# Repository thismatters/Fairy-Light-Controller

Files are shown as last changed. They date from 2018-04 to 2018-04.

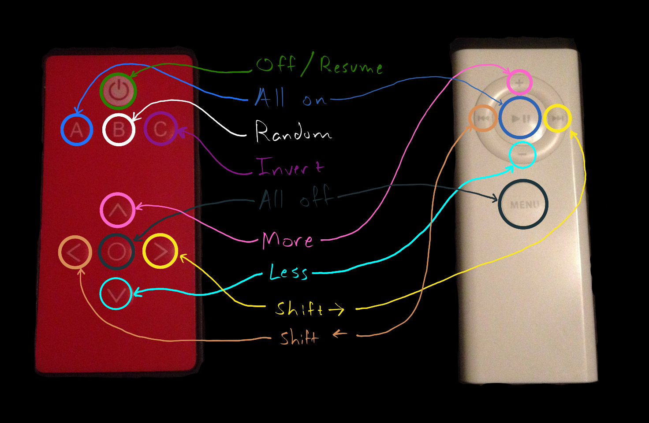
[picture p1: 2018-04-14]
remote_functions.png

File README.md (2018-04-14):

# Fairy Light Controller

Initially when we bought [fairy lights](https://www.amazon.com/gp/product/B00I7M7C40/) (sorry for the amazon link, I hope it stays valid for a while) they came with crappy wall warts which had to be plugged and unplugged daily; these wall warts were of such poor quality that the barrel plug which recieved the light strand would inevitably break. 
Totally unacceptable.
The goal of this project is to provide an easy interface for controlling and powering many strands of LED fairy lights.

## Features

* 40 Watt Power supply,
* ATMega328P,
* IR Reciever and [Remote Control](https://www.sparkfun.com/products/11759) [also works with a little white apple remote if you have one laying around],
* Barrel Plugs for 8 light strands,
* Laser cut acrylic case.

## What's included

* Code for the ATMega328P,
* KiCAD files for the control board ([OSHPark project for this board](https://oshpark.com/shared_projects/VDE5yBSG)),
* Bill of Materials (below),
* SVG files for cutting the case parts.

## Bill of Materials

Here is what you'll need to order to build this thing. I generally order the parts from a few different suppliers due to availability and price so bear with me. You'll also need a board (obvs), you can order some from OSHPark by following the link above, or you can etch your own. Your choice! 

| Part # | Qty | Reference | Description | MFR # (link) | Supplier | Notes |
|---|-----|---|---|---|---|---|
|1|1|C1|Capacitor 100uF (SMD-1206)|[GRM31CD80J107ME39L](https://www.mouser.com/ProductDetail/81-GRM31CD80J107ME9L)|Mouser||
|2|1|C2|Capacitor 10uF (SMD-0805)|[GRM21BC81C106ME15L](https://www.mouser.com/ProductDetail/Murata-Electronics/GRM21BC81C106ME15L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)|Mouser||
|3|1|C3|Capacitor 100nF (SMD-0805)|[100nF 50V 0805](https://www.taydaelectronics.com/100nf-50v-smd-ceramic-chip-capacitor.html)|Tayda|If you order 100 of these they will last you a long time.|
|4|1|C4|Capacitor 1uF (Radial D5L11)|[105CKR100M](https://www.mouser.com/ProductDetail/Illinois-Capacitor-CDE/105CKR100M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)|Mouser||
|5|8|CON1--CON8|Barrel Jack|[KLDX-SMT-0202-AP](https://www.mouser.com/ProductDetail/806-KLDX-SMT0202AP)|Mouser|These are sized to fit the fairy lights linked below.|
|6|1|IC1|Microcontroller|[ATMEGA328P-P](https://www.taydaelectronics.com/atmega328p-pu-atmega328-microcontroller-ic.html)|Tayda|An Arduino chip without the Arduino board. You'll have to have a means to program it (an Arduino board will work nicely for that)|
|7|1|P1|Connector 4POS|[B4PS-VH(LF) (SN)](https://www.digikey.com/product-detail/en/jst-sales-america-inc/B4PS-VH(LF)(SN)/455-1650-ND/926557)|Digi-key|Receive the power onto the board.|
|8|8|Q1--Q8|NPN Darlinton Pair (SOT-223)|[FZT600TA](https://www.mouser.com/ProductDetail/522-FZT600TA)|Mouser||
|9|8|R1--R8|Resistor 0.27 Ohm (Thru-hole)|[MOSX1CT52RR27J](https://www.mouser.com/ProductDetail/660-MOSX1CT52RR27J)|Mouser||
|10|1|R9|Resistor 0 Ohm (SMD-0805)|[0 Ohm 1/8W 1% 0805](https://www.taydaelectronics.com/50-x-smd-chip-resistors-0-ohm-1-8w-1-0805.html)|Tayda|If you order 100 of these they will last you a long time.|
|11|1|R10|Resistor 100 Ohm (SMD-0805)|[100 Ohm 1/8W 1% 0805](https://www.taydaelectronics.com/50-x-smd-chip-resistors-100-ohm-1-8w-1-0805.html)|Tayda|If you order 100 of these they will last you a long time.|
|12|1|R11|Resistor 10k Ohm (SMD-0805)|[10K Ohm 1/8W 1% 0805](https://www.taydaelectronics.com/50-x-smd-chip-resistors-10k-ohm-1-8w-1-0805.html)|Tayda|If you order 100 of these they will last you a long time.|
|13|2|RR1--RR2|Resistor Array (Bussed) 10k Ohm (SIP-9)|[4609X-101-103LF](https://www.mouser.com/ProductDetail/652-4609X-1LF-10K)|Mouser|8 Resistors| 9 Pins|
|14|1|U1|IR Reciever (38 khz)|[TSOP34438](https://www.mouser.com/ProductDetail/522-FZT600TA)|Mouser||
|15|1|X1|Crystal Oscillator (with Caps)|[CSTLS8M00G53-A0](https://www.mouser.com/ProductDetail/81-CSTLS8M00G53-A0)|Mouser||
|16|1|NA|Power Supply 40W|[EPS-45-5-C](https://www.mouser.com/ProductDetail/709-EPS45-5-C)|Mouser||
|17|10|NA|Connector Terminal Crimp-ons|[SVH-41T-P1.1](https://www.digikey.com/product-detail/en/jst-sales-america-inc/SVH-41T-P1.1/455-1319-1-ND/608888)|Digi-key|Those little silver things you have to smash onto your wires.|
|18|2|NA|Connector Housing 4POS|[VHR-4N](https://www.digikey.com/product-detail/en/jst-sales-america-inc/VHR-4N/455-1185-ND/608626)|Digi-key|To get power from the power supply to the board|
|19|1|NA|Connector Housing 3POS|[VHR-3N](https://www.digikey.com/product-detail/en/jst-sales-america-inc/VHR-3N/455-1184-ND/608625)|Digi-key|To get power from the wall to the power supply|
|20|1|NA|Remote Control|[COM-11759](https://www.sparkfun.com/products/11759)|Sparkfun|The software also supports the little white Apple remote control| but the sparkfun one allows more features.|
|21|1|NA|Power Cord||stayonline.com|The power supply insists on being grounded, and I am happy to oblige it. You can use an old PC power cable with one end cut off (choose wisely), or you can order to length.|
|22|8|NA|Fairy Lights|[B00I7M7C40](https://www.amazon.com/gp/product/B00I7M7C40/)|Amazon|It is pretty vital to get the ones with the barrel power connector that matches the barrel jacks (Item 5). Minimum 1, maximum 8|
|23|1|NA|Battery for Remote Control|CR2025|Lots of places|You figure it out|
|24|1|NA|28 pin DIP IC Socket|[28 pin DIP IC Socket](https://www.taydaelectronics.com/28-pin-dip-ic-socket-adaptor-solder-type.html)|Tayda|This is what you'll actually solder to the board. Cram the ATMega328 into this.

## The Case

The case is cut from 0.177 inch thick acyrlic sheet using a laser cutter. The [specific laser cutter](http://atxhs.org/wiki/Hosted/10000045) I used is at the ATX Hackerspace; it does not compensate for kerf so the files themselves compensate for the laser width. The case parts should fit together snugly so no adhesive is needed for assembly, although the little bits for wall mounting will need to be bonded onto the bottom so a little cyanoacrylate adhesive will be useful.

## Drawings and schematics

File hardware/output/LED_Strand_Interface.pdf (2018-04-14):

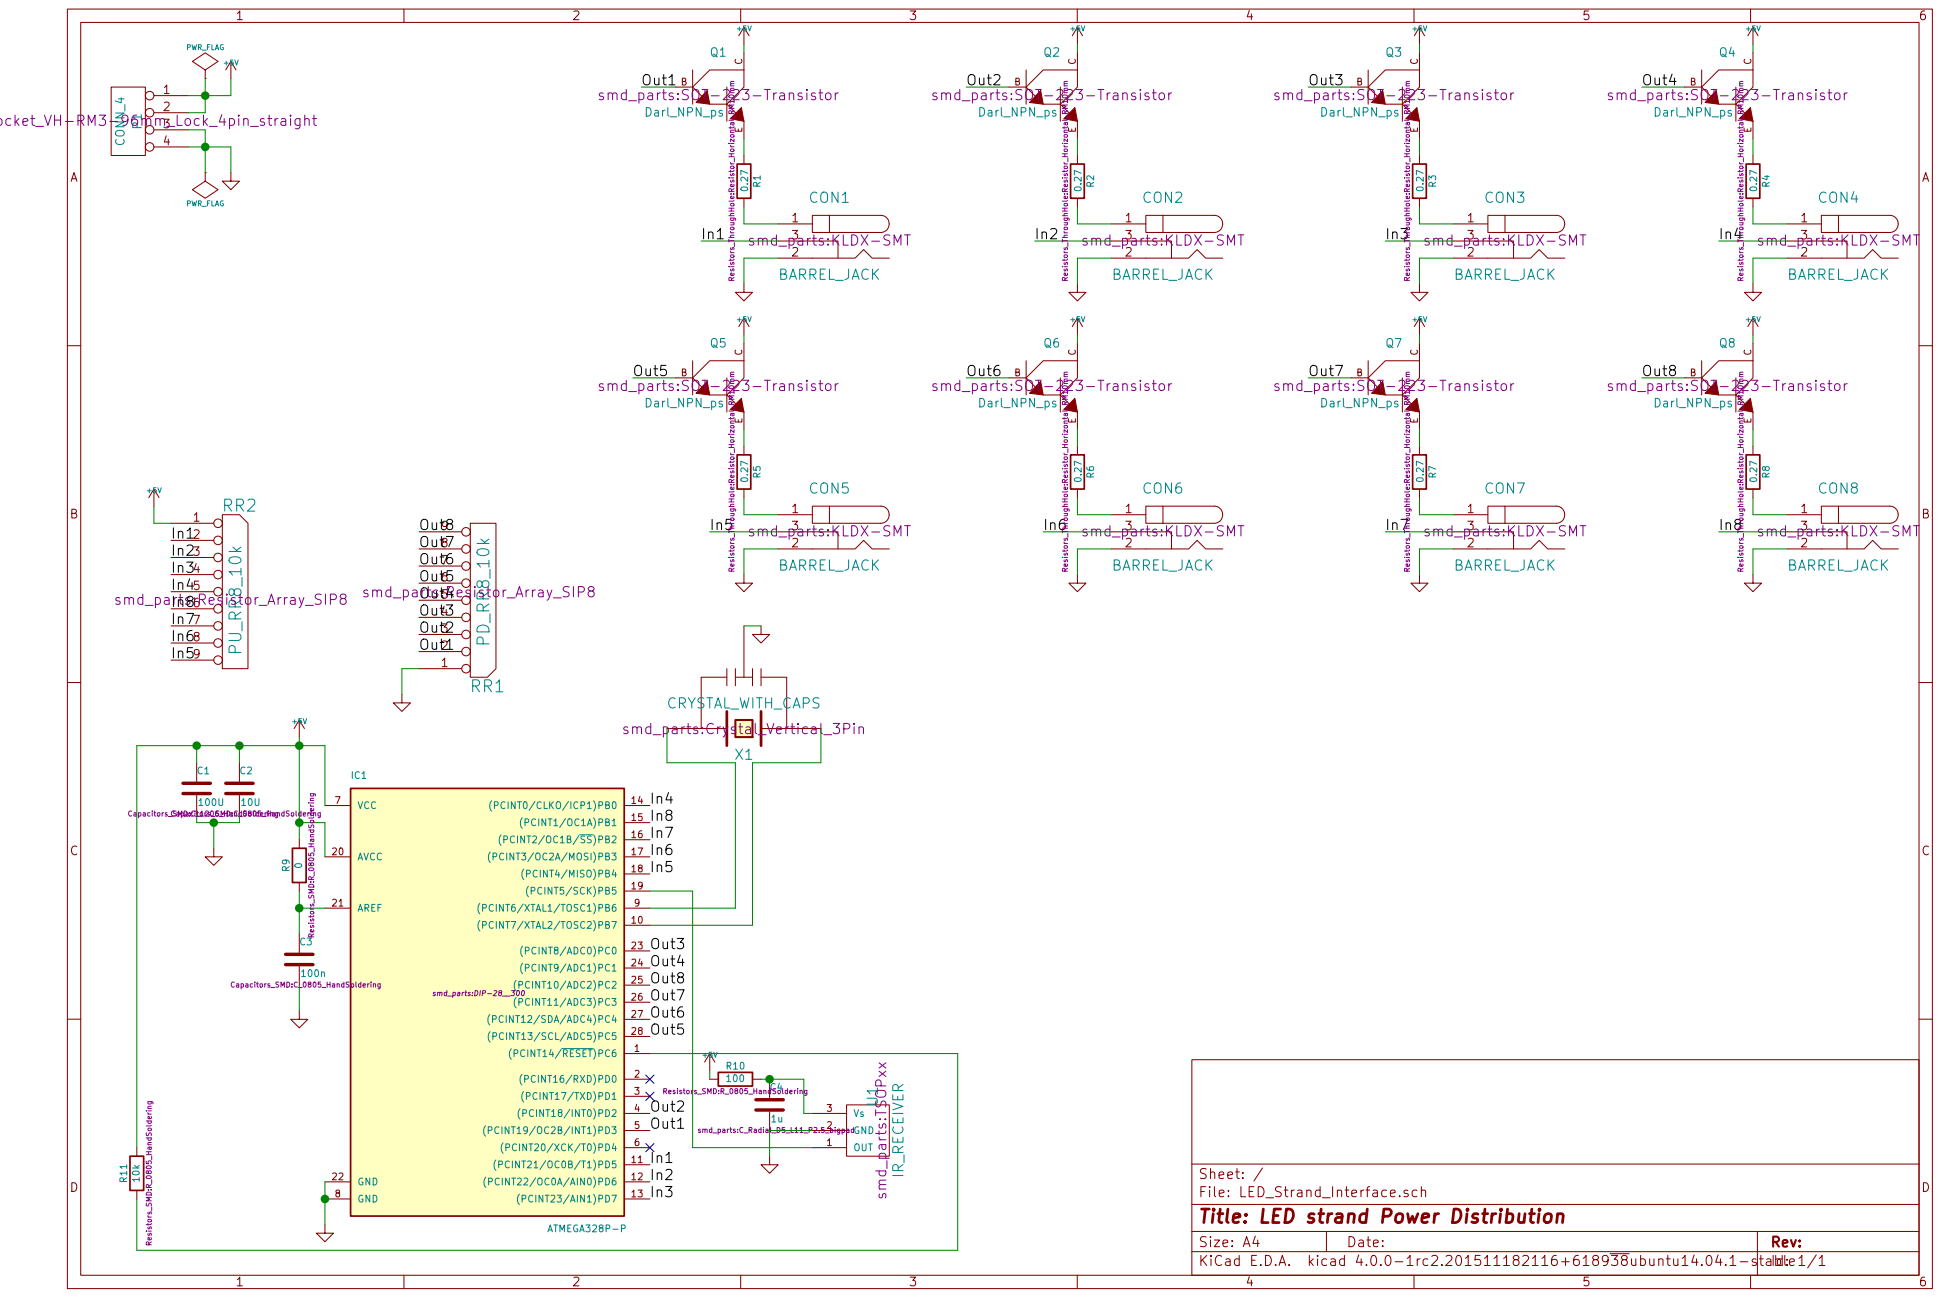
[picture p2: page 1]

File: LED_Strand_Interface.sch Sheet: /
Id: 1/1 Title: LED strand Power Distribution

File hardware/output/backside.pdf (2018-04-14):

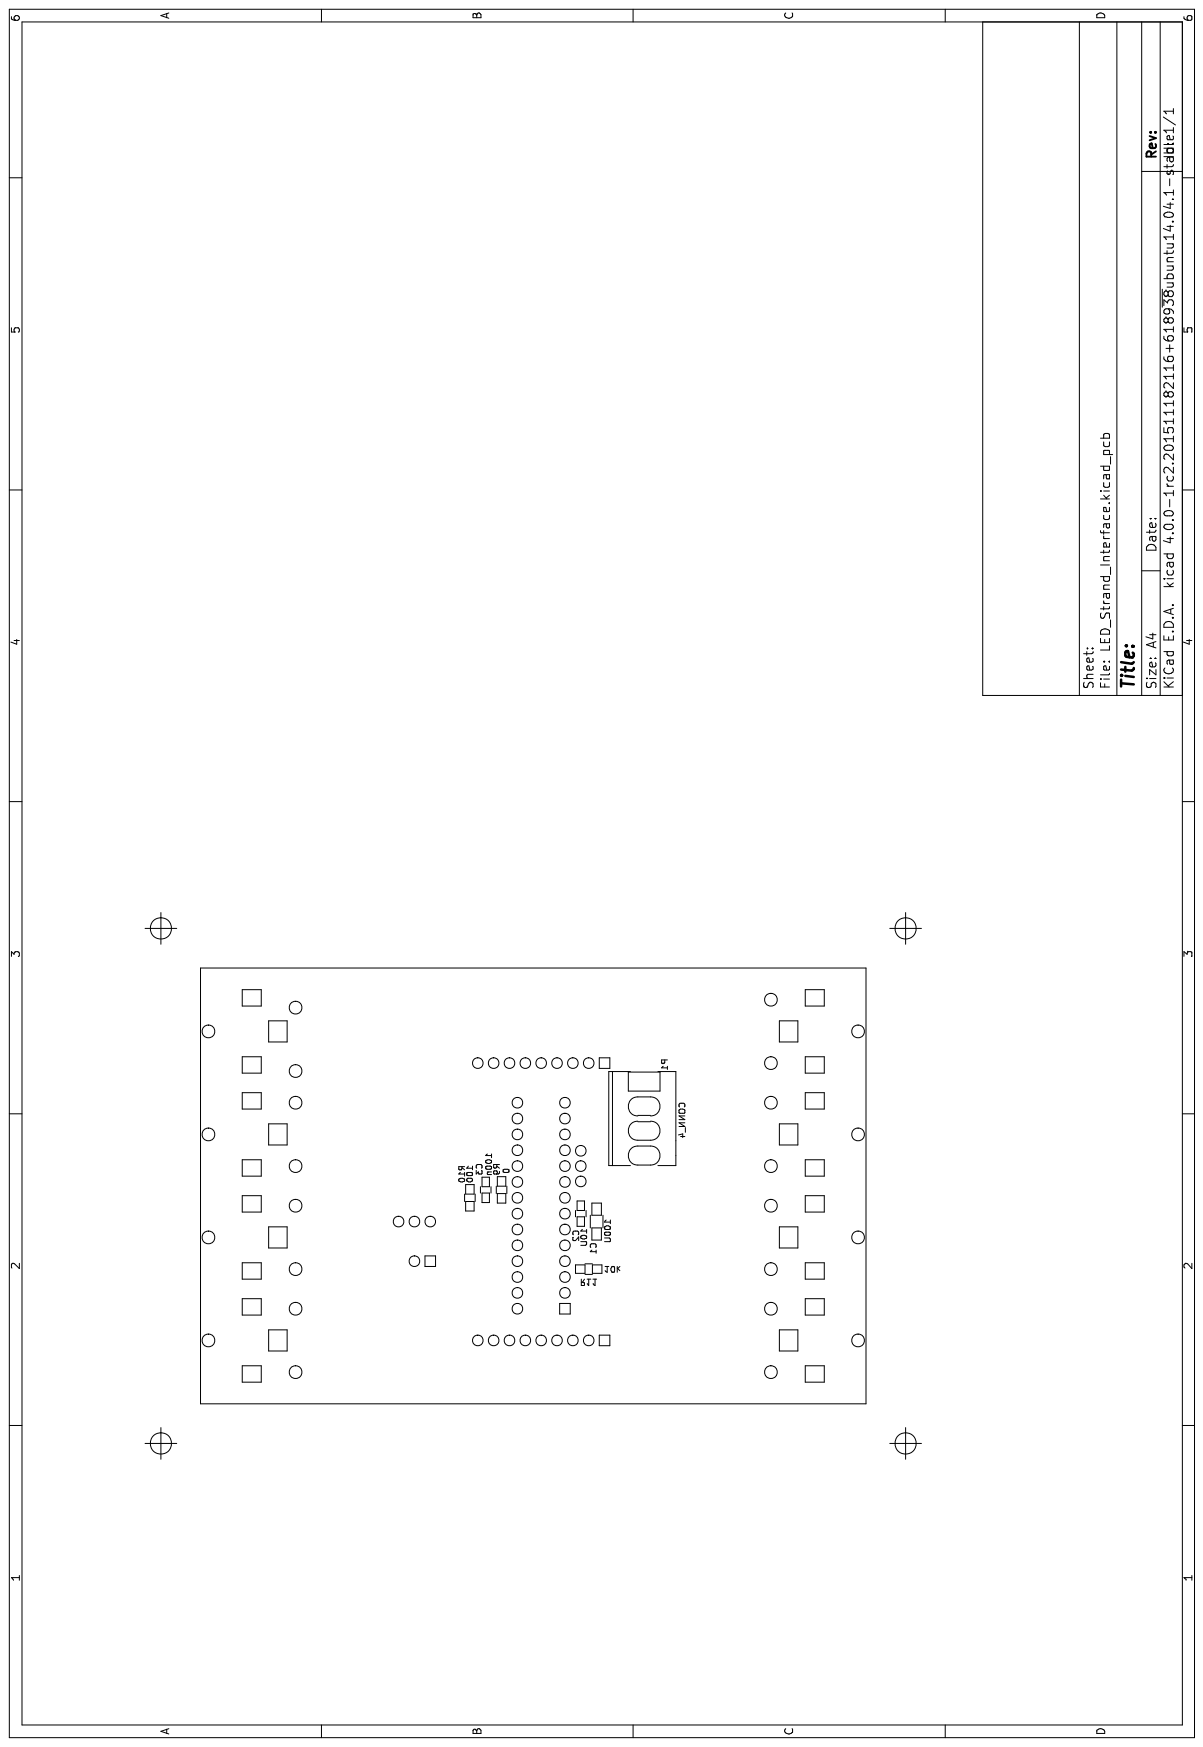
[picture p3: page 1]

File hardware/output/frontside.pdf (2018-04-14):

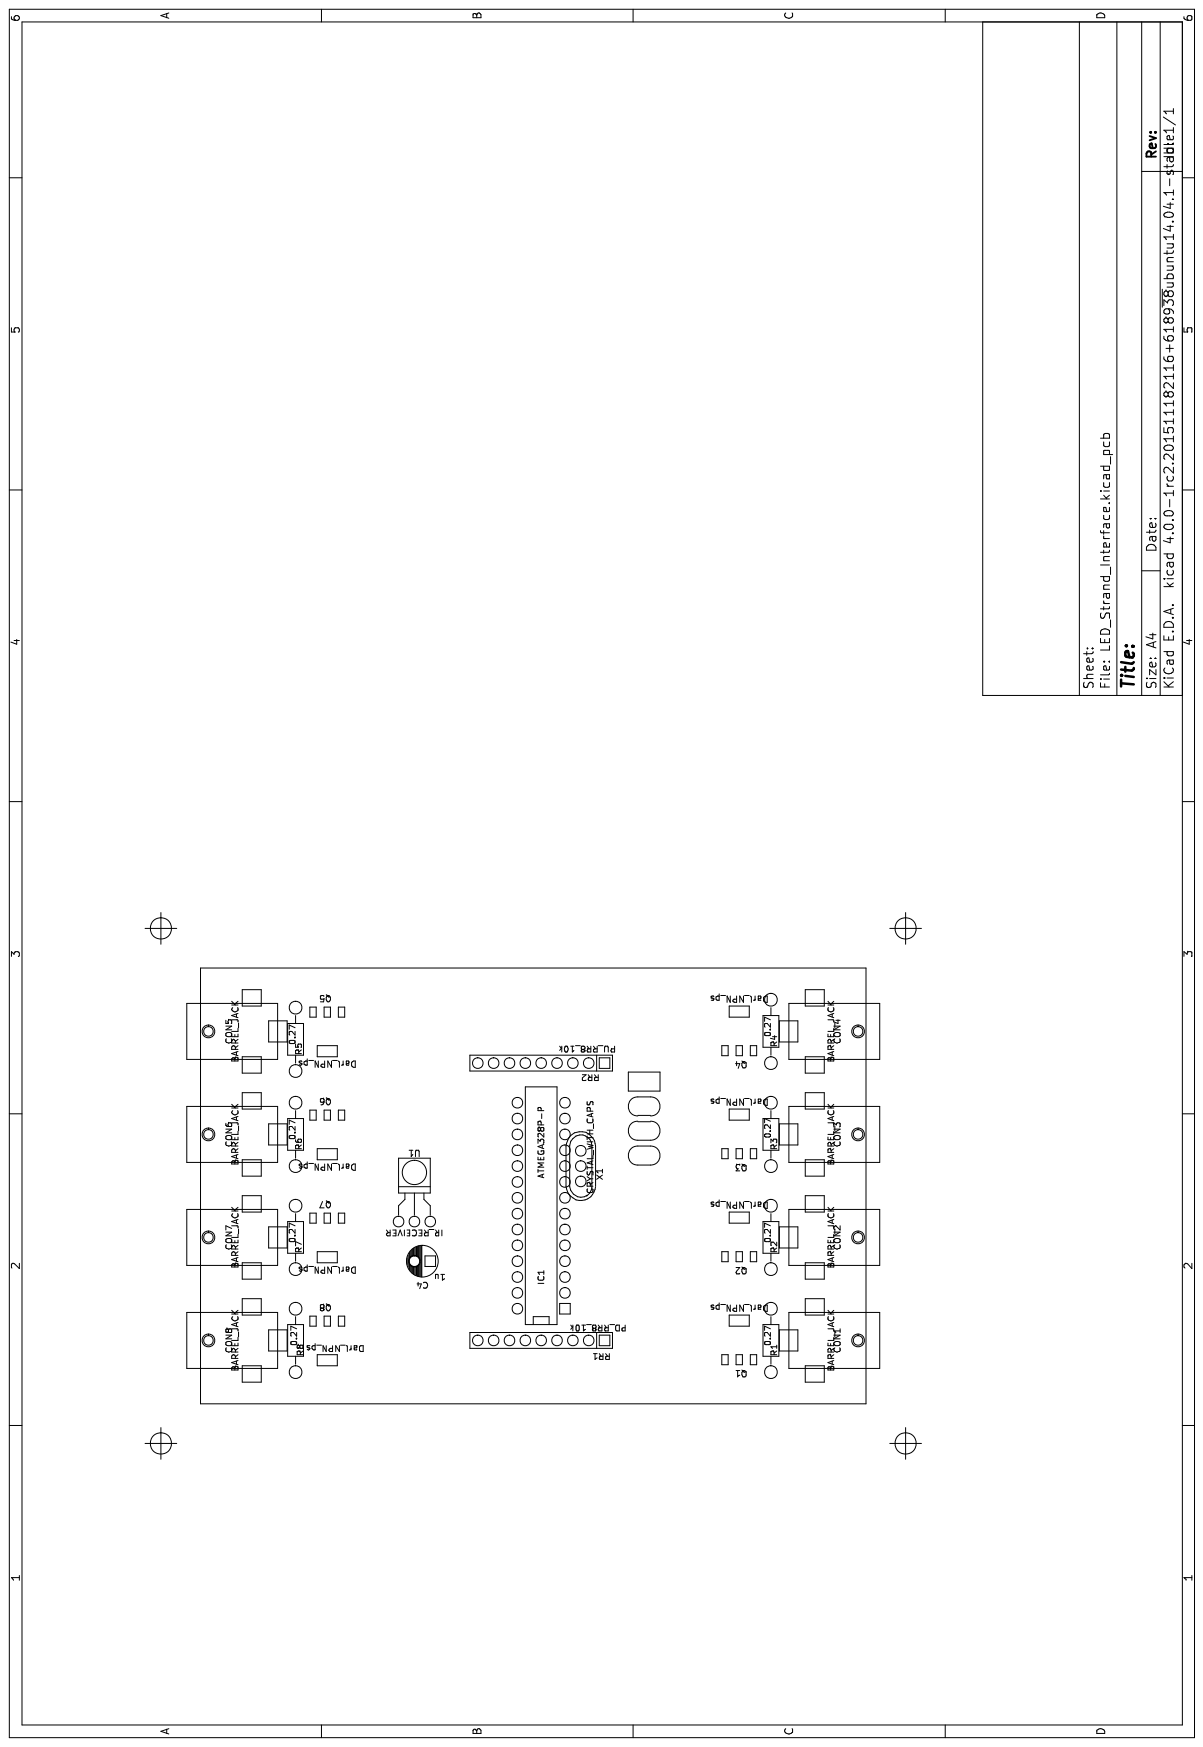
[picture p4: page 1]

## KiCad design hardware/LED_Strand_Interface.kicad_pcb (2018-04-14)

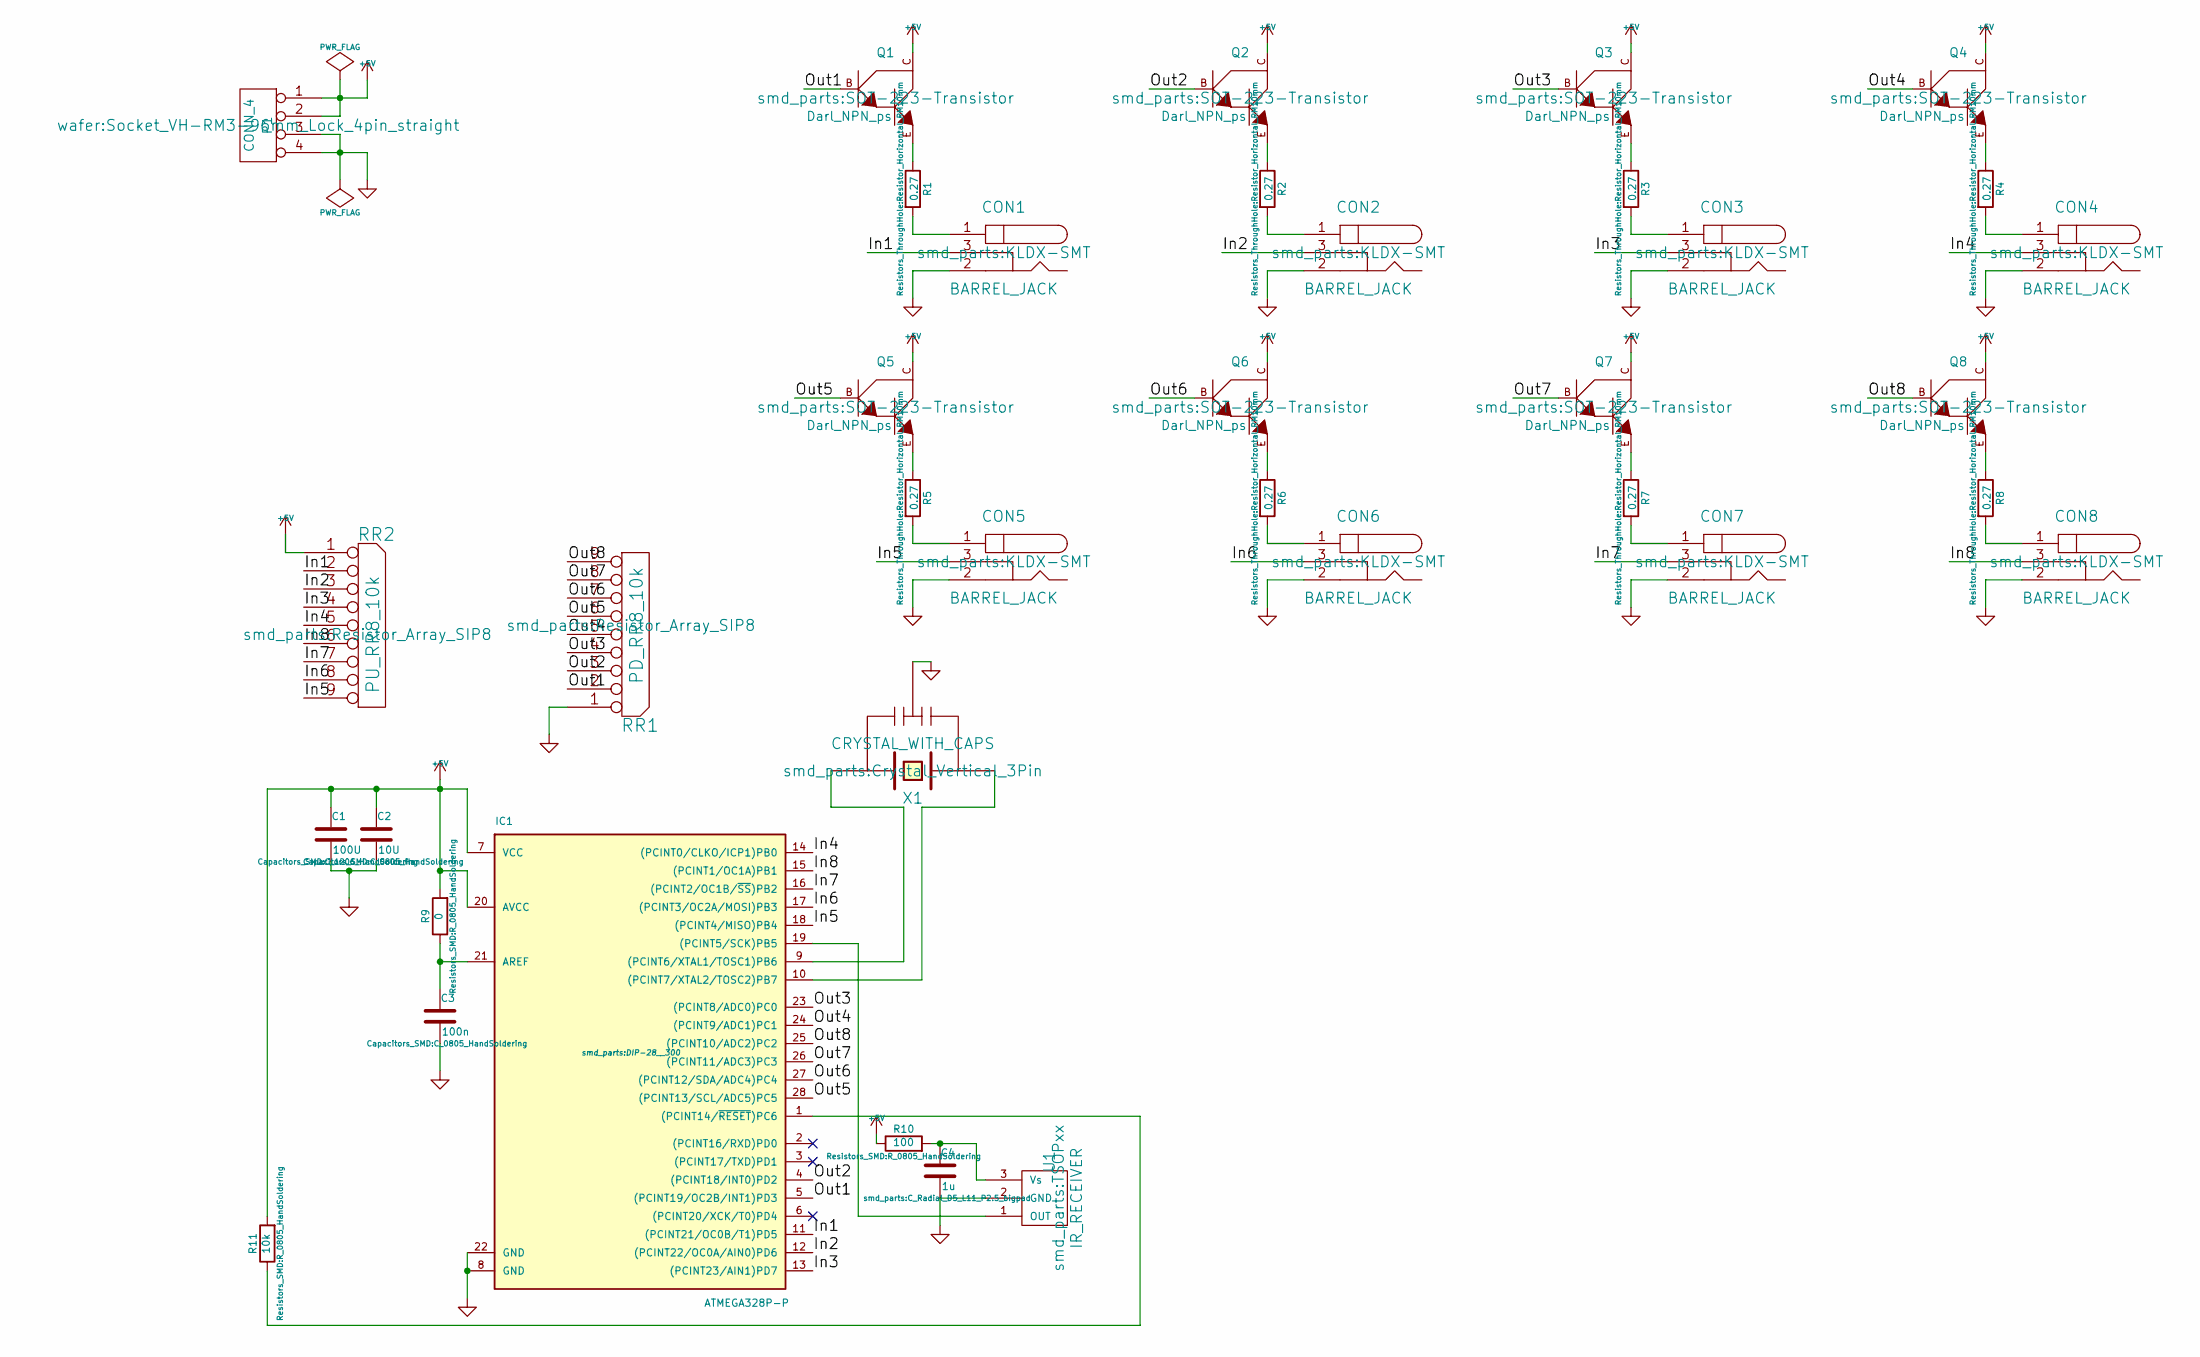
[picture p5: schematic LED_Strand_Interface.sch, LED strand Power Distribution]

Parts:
C1: 100U; C_1206_HandSoldering
C2: 10U; C_0805_HandSoldering
C3: 100n; C_0805_HandSoldering
C4: 1u; C_Radial_D5_L11_P2.5_bigpad
CON1, CON2, CON3, CON4, CON5, CON6, CON7, CON8: BARREL_JACK; KLDX-SMT
IC1: ATMEGA328P-P; DIP-28__300
P1: CONN_4; Socket_VH-RM3-96mm_Lock_4pin_straight
Q1, Q2, Q3, Q4, Q5, Q6, Q7, Q8: Darl_NPN_ps; SOT-223-Transistor
R1, R2, R3, R4, R5, R6, R7, R8: 0.27; Resistor_Horizontal_RM10mm
R9: 0; R_0805_HandSoldering
R10: 100; R_0805_HandSoldering
R11: 10k; R_0805_HandSoldering
RR1: PD_RR8_10k; Resistor_Array_SIP8
RR2: PU_RR8_10k; Resistor_Array_SIP8
U1: IR_RECEIVER; TSOPxx
X1: CRYSTAL_WITH_CAPS; Crystal_Vertical_3Pin

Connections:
+5V: C1.1, C2.1, IC1.7 (VCC), IC1.20 (AVCC), P1.1, P1.2, Q1.C, Q2.C, Q3.C, Q4.C, Q5.C, Q6.C, Q7.C, Q8.C, R9.2, R10.1, R11.2, RR2.1 (COM)
/In1: CON1.3, IC1.11 ((PCINT21/OC0B/T1)PD5), RR2.2
/In2: CON2.3, IC1.12 ((PCINT22/OC0A/AIN0)PD6), RR2.3
/In3: CON3.3, IC1.13 ((PCINT23/AIN1)PD7), RR2.4
/In4: CON4.3, IC1.14 ((PCINT0/CLKO/ICP1)PB0), RR2.5
/In5: CON5.3, IC1.18 ((PCINT4/MISO)PB4), RR2.9
/In6: CON6.3, IC1.17 ((PCINT3/OC2A/MOSI)PB3), RR2.8
/In7: CON7.3, IC1.16 ((PCINT2/OC1B/~SS~)PB2), RR2.7
/In8: CON8.3, IC1.15 ((PCINT1/OC1A)PB1), RR2.6
/Out1: IC1.5 ((PCINT19/OC2B/INT1)PD3), Q1.B, RR1.2
/Out2: IC1.4 ((PCINT18/INT0)PD2), Q2.B, RR1.3
/Out3: IC1.23 ((PCINT8/ADC0)PC0), Q3.B, RR1.4
/Out4: IC1.24 ((PCINT9/ADC1)PC1), Q4.B, RR1.5
/Out5: IC1.28 ((PCINT13/SCL/ADC5)PC5), Q5.B, RR1.6
/Out6: IC1.27 ((PCINT12/SDA/ADC4)PC4), Q6.B, RR1.7
/Out7: IC1.26 ((PCINT11/ADC3)PC3), Q7.B, RR1.8
/Out8: IC1.25 ((PCINT10/ADC2)PC2), Q8.B, RR1.9
GND: C1.2, C2.2, C3.2, C4.2, CON1.2, CON2.2, CON3.2, CON4.2, CON5.2, CON6.2, CON7.2, CON8.2, IC1.8 (GND), IC1.22 (GND), P1.3, P1.4, RR1.1 (COM), U1.2 (GND), X1.2 (GND)
unnamed: C3.1, IC1.21 (AREF), R9.1
unnamed: C4.1, R10.2, U1.3 (Vs)
unnamed: CON1.1, R1.2
unnamed: CON2.1, R2.2
unnamed: CON3.1, R3.2
unnamed: CON4.1, R4.2
unnamed: CON5.1, R5.2
unnamed: CON6.1, R6.2
unnamed: CON7.1, R7.2
unnamed: CON8.1, R8.2
unnamed: IC1.1 ((PCINT14/~RESET~)PC6), R11.1
unnamed: IC1.9 ((PCINT6/XTAL1/TOSC1)PB6), X1.3
unnamed: IC1.10 ((PCINT7/XTAL2/TOSC2)PB7), X1.1
unnamed: IC1.19 ((PCINT5/SCK)PB5), U1.1 (OUT)
unnamed: Q1.E, R1.1
unnamed: Q2.E, R2.1
unnamed: Q3.E, R3.1
unnamed: Q4.E, R4.1
unnamed: Q5.E, R5.1
unnamed: Q6.E, R6.1
unnamed: Q7.E, R7.1
unnamed: Q8.E, R8.1

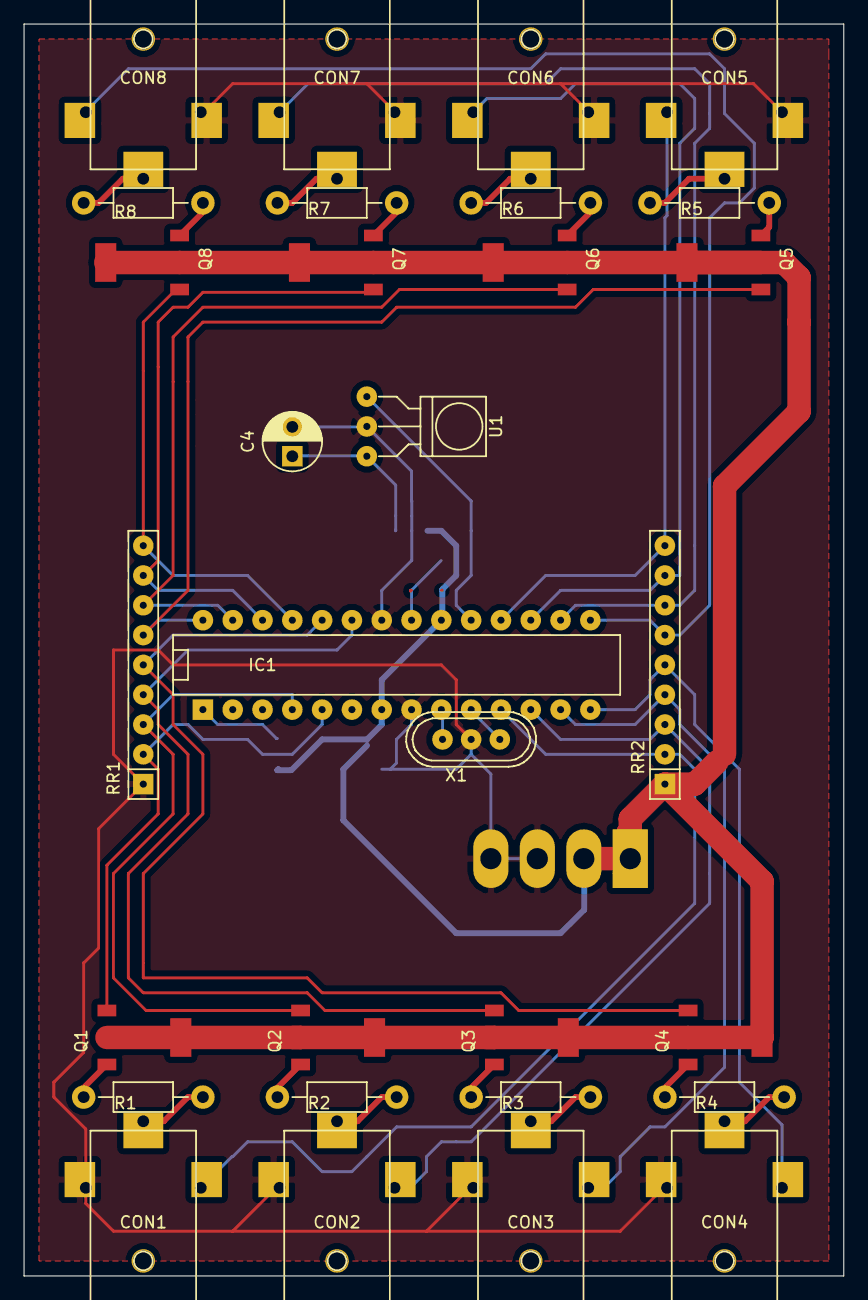
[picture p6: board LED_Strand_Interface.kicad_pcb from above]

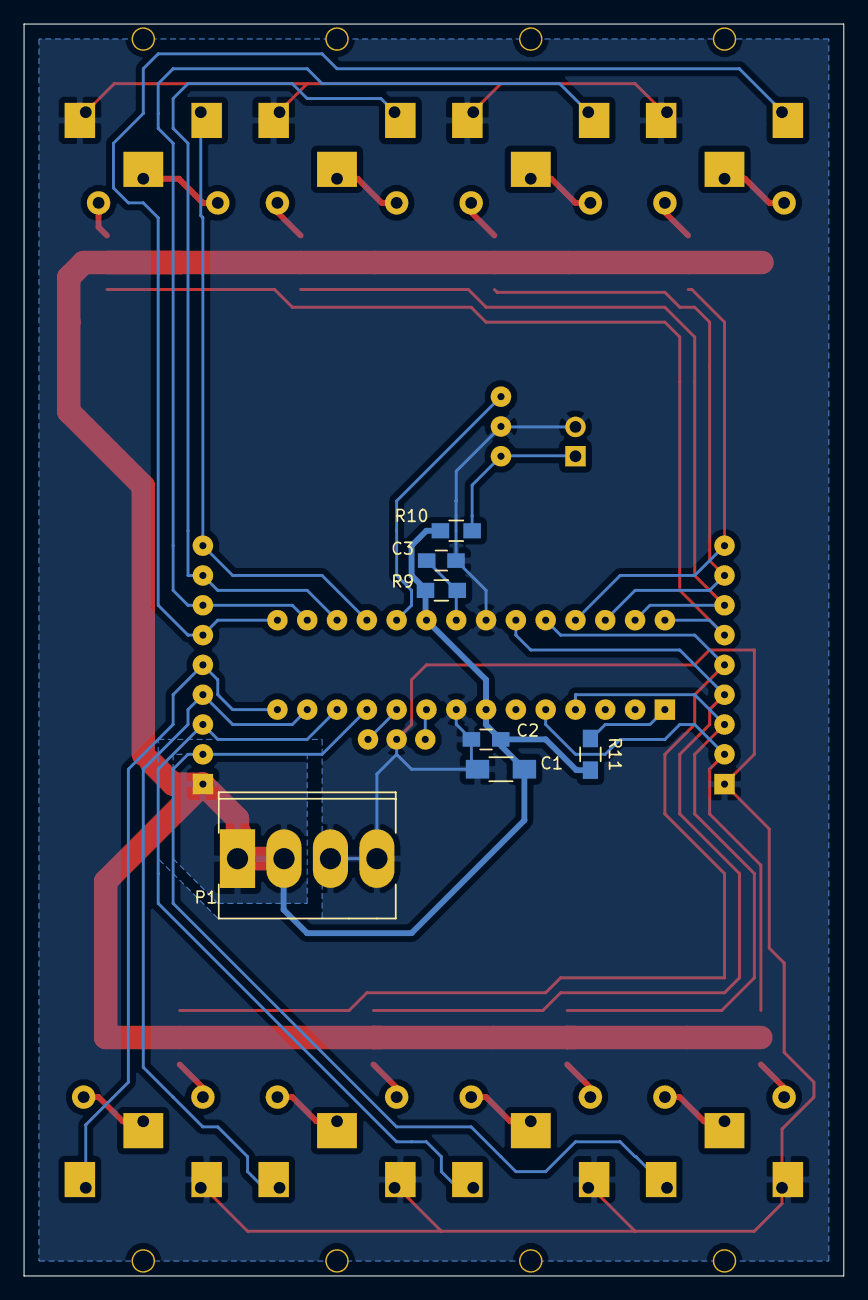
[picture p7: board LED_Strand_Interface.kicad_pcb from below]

Board: 2 copper layers, 69.8 x 106.7 mm, 37 parts (7 on the bottom side), 40 nets.

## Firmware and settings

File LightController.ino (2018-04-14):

#define F_CPU 8000000
#define   N   8
#include  <IRremote.h> 

int RECV_PIN = 13;
IRrecv irrecv(RECV_PIN);
decode_results ir_results;
int feedback_pins[N] = {5, 6, 7, 8, 12, 11, 10, 9};
int output_pins[N] = {3, 2, A0, A1, A5, A4, A3, A2};

boolean lights_on[N];
boolean lights_in[N];
boolean saved_state[N];
boolean something_changed = true;

int delay_ms = 100;
int long_wait_time = 100;
int short_wait_time = 50;
int cycles_since_ir_input = 0;
long last_action = 0;
int lights_on_count = 0;

void update_lights_in() {
    for (int i=0; i<N; i++) {
        if (digitalRead(feedback_pins[i])) {
            lights_in[i] = true;
        } else {
            lights_in[i] = false;
            lights_on[i] = false;
        }
    }
}

void shift_forward(boolean next_light_state) {
    boolean temp = false;
    for (int i=0; i<N; i++) {
        if (lights_in[i]) {
            temp = lights_on[i];
            lights_on[i] = next_light_state;
            next_light_state = temp;
        } else {
            lights_on[i] = false;
        }
    }
}

void shift_backward() {
    boolean prev_light_state = false;
    boolean temp = false;
    for (int i=N-1; i>=0; i--) {
        if (lights_in[i]) {
            temp = lights_on[i];
            lights_on[i] = prev_light_state;
            prev_light_state = temp;
        } else {
            lights_on[i] = false;
        }
    }
}

void all_on() {
    for (int i=0; i<N; i++) {
        if (lights_in[i]) {
            lights_on[i] = true;
        }
    }
}

void all_off() {
    for (int i=0; i<N; i++) {
       lights_on[i] = false;
    }
}

void toggle_power() {
    if (lights_on_count == 0) {
        for (int i=0; i<N; i++) { 
            if (lights_in[i]) {
                lights_on[i] = saved_state[i];
            } else {
                lights_on[i] = false;
            }
        }
    } else {
        for (int i=0; i<N; i++) { 
            if (lights_in[i]) {
                saved_state[i] = lights_on[i];
            } else {
                saved_state[i] = false;
            }
            lights_on[i] = false;
        }
    }
}

void invert() {
    for (int i=0; i<N; i++) {
        if (lights_in[i]) {
            lights_on[i] = !lights_on[i];
        } else {
            lights_on[i] = false;
        }
    }
}

void random_sequence() {
    for (int i=0; i<N; i++) {
        lights_on[i] = false;
        if (lights_in[i]) {
            if (random(2) == 1){
                lights_on[i] = true;
            }
        }
    }
}

void enact() {
    int write_val = 0;
    something_changed = false;
    lights_on_count = 0;
    for (int i=0; i<N; i++) {
        write_val = 0;
        if (lights_on[i] && lights_in[i]) {
            write_val = 1;
            lights_on_count++;
        } else {
            lights_on[i] = false;
        }
        if (digitalRead(output_pins[i]) != write_val) {
            digitalWrite(output_pins[i], write_val);
            something_changed = true;
        }
    }
}

void represent_output(char string_representation[]) {
    for (int i=0; i<N; i++) {
        string_representation[i] = 'N';
        if (lights_in[i]) {
            string_representation[i] = '0';
            if (lights_on[i]) {
                string_representation[i] = '1';
            }
        }
    }
}

void setup() {
    for (int i=0; i<N; i++) {
        pinMode(feedback_pins[i], INPUT);
        pinMode(output_pins[i], OUTPUT);
        lights_on[i] = false;
        lights_in[i] = false;
    }
    irrecv.resume();
    irrecv.enableIRIn();
    // Serial.begin(115200);
    // Serial.flush();
    randomSeed(203);
}

void loop() {
    update_lights_in();
    if (irrecv.decode(&ir_results)) {
        long actionable = 0;  
        actionable = ir_results.value;
        // Serial.println(actionable, HEX);
        // Serial.flush();
        if (actionable == 0xFFFFFFFF) {
            actionable = last_action;    
        }
        switch (actionable) {
            case 0x77E150EF:  // plus (Apple)
            case 0x10EFA05F:  // plus (sparkfun [^])
                shift_forward(true);
                break;
            case 0x77E160EF:  // forward (Apple)
            case 0x10EF807F:  // forward (sparkfun [>])
                shift_forward(false);
                break;
            case 0x77E130EF:  // minus (Apple)
            case 0x10EF00FF:  // minus (sparkfun [v])
                shift_backward();
                break;
            case 0x77E190EF:  // backward (Apple)
            case 0x10EF10EF:  // backward (sparkfun [<])
                shift_backward();
                break;
            case 0x77E1A0EF:  // bright (Apple [playpause])
            case 0x10EFF807:  // bright (sparkfun [A])
                all_on();
                break;
            case 0x77E1C0EF:  // dark (Apple [menu])
            case 0x10EF20DF:  // dark (sparkfun [O])
                all_off();
                break;
            case 0x10EFD827:  // power (sparkfun)
                toggle_power();
                break;
            case 0x10EF58A7:  // invert (sparkfun [C])
                invert();
                break;
            case 0x10EF7887:  // random (sparkfun [B]) 
                random_sequence();
                break;
            default:
                break;
        }
        last_action = actionable;
        irrecv.resume();
        delay_ms = short_wait_time;
        cycles_since_ir_input = 0;
    } else {
        if (delay_ms != long_wait_time) {
            if (cycles_since_ir_input > 50) {
                delay_ms = long_wait_time;
                last_action = 0;
            }
            cycles_since_ir_input++;
        }
    }
    enact();
    // Serial.println("Working");
    delay(delay_ms);
}

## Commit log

2018-04-14 updated BOM added photo describing remote control functions
2018-04-14 added readme section for the case
